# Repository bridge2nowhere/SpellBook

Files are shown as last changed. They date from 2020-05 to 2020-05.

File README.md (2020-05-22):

# SpellBook



Tabletop SpellBook for Dungeons and Dragons 5e.

This Arduino project keeps track of spell slots and spell text without having to have a phone out, spell cards, or a stack of paper/book.

# Hardware
* [Adafruit M0 Adalogger](https://www.adafruit.com/product/2796)
* [Adafruit Sharp Memory Display Breakout Board](https://www.adafruit.com/product/3502)
* [Adafruit 8x8 Mini Led Matrix with I2C backpack](https://www.adafruit.com/product/871)
* [2.7" Sharp Memory Display](https://www.digikey.com/product-detail/en/sharp-microelectronics/LS027B7DH01A/425-2908-ND/5054067) replacing the one that comes on the breakout board
* [KY-040 Rotary Encoder](https://www.aliexpress.com/item/33041814942.html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,searchweb201602_,searchweb201603_)
* [19mm Push Button](https://www.aliexpress.com/item/4000072167036.html?spm=a2g0s.9042311.0.0.64814c4dvVELMQ)
* MicroSD card

# Software
* Currently, spells data is stored in a JSON file on an SD card and parsed into spell objects in the program.
* The rotary encoder rotation moves through slots and levels (depending on rotation direction)
* When you click the encoder button it will switch to the spell side, where rotation rotates through the spells.

# 3D Printed Shell & 
* 3D printed shell is in two parts. The base still needs some work, I would like to line up the USB to the hole in the back.
* M3 Thumb Screws [amazon link](https://www.amazon.com/gp/product/B06XQBPD4Z/ref=ppx_yo_dt_b_asin_title_o04_s01?ie=UTF8&psc=1)
* 50mm donut semiprecious gemstone pendant for the knob [eBay link](https://www.ebay.com/itm/50mm-Round-Donut-Ring-Gemstone-Pendant-Loose-Beads-1pc-6-Materials-Selectable/390793341631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)
* 18x25mm semiprecious oval cabochons for the upper back panel [amazon link](https://www.amazon.com/gp/product/B07WZXCKFW/ref=ppx_yo_dt_b_asin_title_o04_s01?ie=UTF8&psc=1)
* 



# Future Plans
* Add a way to do long rests
* Adding a way to mark spells as prepared prepare spells to shorten the list.

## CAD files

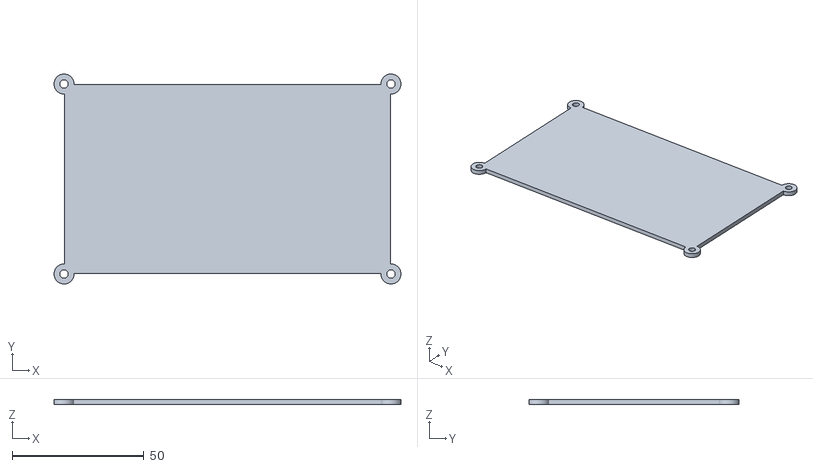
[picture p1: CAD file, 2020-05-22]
STL files/Bottom Plate v4.stl
131.9 x 79.8 x 2.00

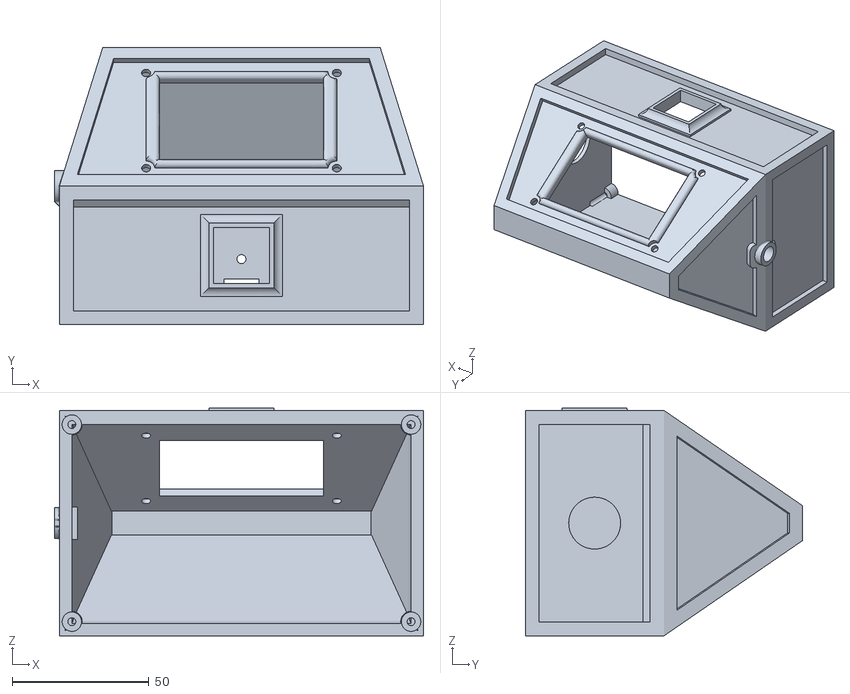
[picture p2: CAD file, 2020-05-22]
STL files/Big Screen v4.stl
135.2 x 101.6 x 83.4

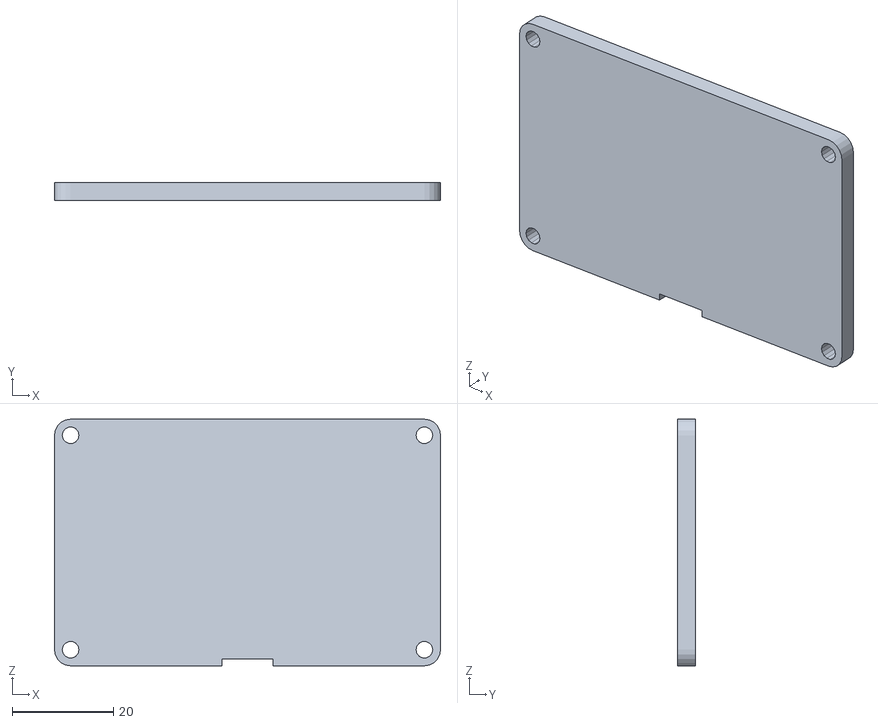
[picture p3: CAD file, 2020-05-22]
STL files/LCD Tray v2.stl
76.2 x 3.50 x 48.7

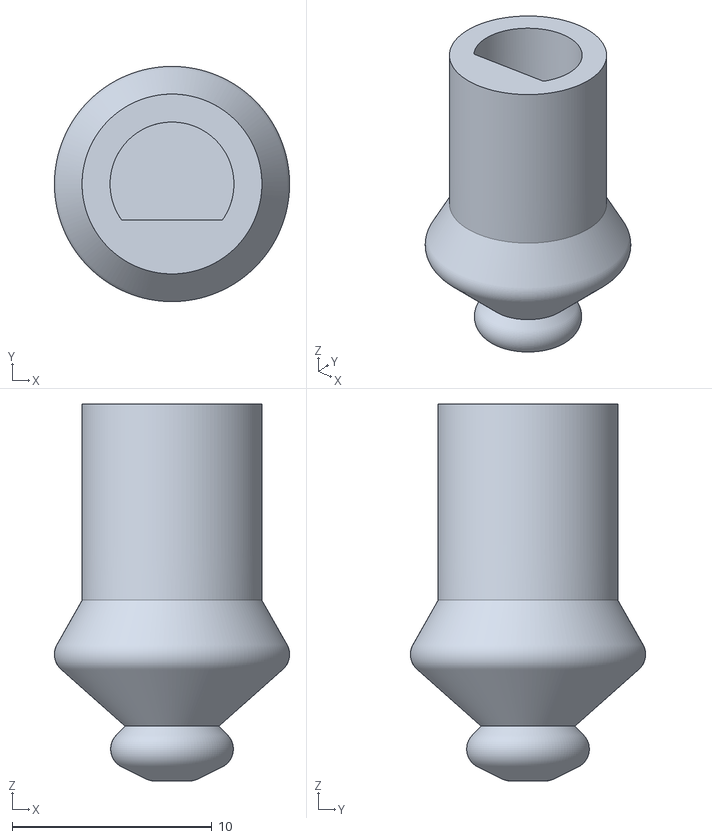
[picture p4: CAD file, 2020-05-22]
STL files/Jaspar Knob Body.stl
11.8 x 11.8 x 18.9

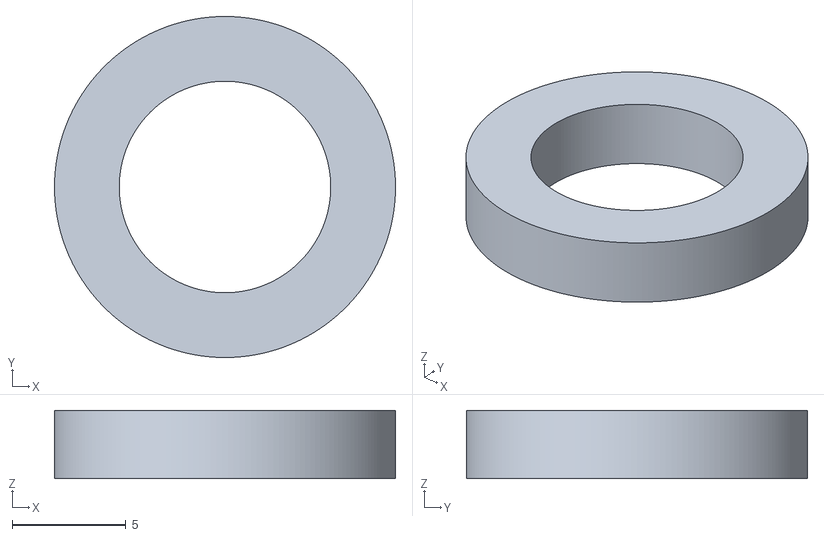
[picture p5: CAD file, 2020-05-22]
STL files/Jaspar Washer.stl
15.0 x 15.0 x 3.00

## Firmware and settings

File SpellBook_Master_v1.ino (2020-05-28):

#include <Adafruit_SharpMem.h>

#include <ArduinoJson.h>
#include "Spell.h"
#include <Wire.h>
#include <Adafruit_GFX.h>
#include <RotaryEncoder.h>
#include "Adafruit_LEDBackpack.h"
#include <Fonts/FreeSansBold12pt7b.h>
#include <Fonts/FreeSansBold9pt7b.h>
#include <Fonts/FreeSans9pt7b.h>
#include <SPI.h>
#include <SD.h>
#include <StreamUtils.h>


#define ENCODER_BUTT 6 //sw
#define ENCODER_1 5 //clk
#define ENCODER_2 9 //dt

#define SHARP_SCK  13
#define SHARP_MOSI 12
#define SHARP_SS   11

#define BLACK 0
#define WHITE 1

#define SILVER_BUTT A0

const int SPELLCOUNT = 21;
const PROGMEM char* fileNames[SPELLCOUNT] = {"0MENDING.TXT","0SACRE~1.TXT","0SPRDYIN.TXT","0THAUMAT.TXT","0TOLLDED.TXT","1DETGOOD.TXT","1DETMAGC.TXT","1DETPOSN.TXT","1GUDBOLT.TXT","1HEALWRD.TXT","1INFWOUN.TXT","1PROEVIL.TXT","1PURFOOD.TXT","1SANCTUR.TXT","1SHLDFTH.TXT","1BANE000.TXT","1BLESS000.TXT","1CEREMNY.TXT","1COMMA~1.TXT","1CRTWATR.TXT","1CUREWND.TXT"}; 

const unsigned char habbakukRelic [] PROGMEM = {
  // 'Reliquarry Picture 2, 400x240px
  0xff, 0xff, 0xff, 0xff, 0xff, 0xff, 0xff, 0xff, 0xff, 0xff, 0xff, 0xff, 0xff, 0xff, 0xff, 0xff, 
  0xff, 0xff, 0xff, 0xff, 0xff, 0xff, 0xff, 0xff, 0xff, 0xff, 0xff, 0xff, 0xff, 0xff, 0xff, 0xff, 
  0xff, 0xff, 0xff, 0xff, 0xff, 0xff, 0xff, 0xff, 0xff, 0xff, 0xff, 0xff, 0xff, 0xff, 0xff, 0xff, 
  0xff, 0xff, 0xff, 0xff, 0xff, 0xff, 0xff, 0xff, 0xff, 0xff, 0xff, 0xff, 0xff, 0xff, 0xff, 0xff, 
  0xff, 0xff, 0xff, 0xff, 0xff, 0xff, 0xff, 0xff, 0xff, 0xff, 0xff, 0xff, 0xff, 0xff, 0xff, 0xff, 
  0xff, 0xff, 0xff, 0xff, 0xff, 0xff, 0xff, 0xff, 0xff, 0xff, 0xff, 0xff, 0xff, 0xff, 0xff, 0xff, 
  0xff, 0xff, 0xff, 0xff, 0xff, 0xff, 0xff, 0xff, 0xff, 0xff, 0xff, 0xff, 0xff, 0xff, 0xff, 0xff, 
  0xff, 0xff, 0xff, 0xff, 0xff, 0xff, 0xff, 0xff, 0xff, 0xff, 0xff, 0xff, 0xff, 0xff, 0xff, 0xff, 
  0xff, 0xff, 0xff, 0xff, 0xff, 0xff, 0xff, 0xff, 0xff, 0xff, 0xff, 0xff, 0xff, 0xff, 0xff, 0xff, 
  0xff, 0xff, 0xff, 0xff, 0xff, 0xff, 0xff, 0xff, 0xff, 0xff, 0xff, 0xff, 0xff, 0xff, 0xff, 0xff, 
  0xff, 0xff, 0xff, 0xff, 0xff, 0xff, 0xff, 0xff, 0xff, 0xff, 0xff, 0xff, 0xff, 0xff, 0xff, 0xff, 
  0xff, 0xff, 0xff, 0xff, 0xff, 0xff, 0xff, 0xff, 0xff, 0xff, 0xff, 0xff, 0xff, 0xff, 0xff, 0xff, 
  0xff, 0xff, 0xff, 0xff, 0xff, 0xff, 0xff, 0xff, 0xff, 0xff, 0xff, 0xff, 0xff, 0xff, 0xff, 0xff, 
  0xff, 0xff, 0xff, 0xff, 0xff, 0xff, 0xff, 0xff, 0xff, 0xff, 0xff, 0xff, 0xff, 0xff, 0xff, 0xff, 
  0xff, 0xff, 0xff, 0xff, 0xff, 0xff, 0xff, 0xff, 0xff, 0xff, 0xff, 0xff, 0xff, 0xff, 0xff, 0xff, 
  0xff, 0xff, 0xff, 0xff, 0xff, 0xff, 0xff, 0xff, 0xff, 0xff, 0xff, 0xff, 0xff, 0xff, 0xff, 0xff, 
  0xff, 0xff, 0xff, 0xff, 0xff, 0xff, 0xff, 0xff, 0xff, 0xff, 0xff, 0xff, 0xff, 0xff, 0xff, 0xff, 
  0xff, 0xff, 0xff, 0xff, 0xff, 0xff, 0xff, 0xff, 0xff, 0xff, 0xff, 0xff, 0xff, 0xff, 0xff, 0xff, 
  0xff, 0xff, 0xff, 0xff, 0xff, 0xff, 0xff, 0xff, 0xff, 0xff, 0xff, 0xff, 0xff, 0xff, 0xff, 0xff, 
  0xff, 0xff, 0xff, 0xff, 0xff, 0xff, 0xff, 0xff, 0xff, 0xff, 0xff, 0xff, 0xff, 0xff, 0xff, 0xff, 
  0xff, 0xff, 0xff, 0xff, 0xff, 0xff, 0xff, 0xff, 0xff, 0xff, 0xff, 0xff, 0xff, 0xff, 0xff, 0xff, 
  0xff, 0xff, 0xff, 0xff, 0xff, 0xff, 0xff, 0xff, 0xff, 0xff, 0xff, 0xff, 0xff, 0xff, 0xff, 0xff, 
  0xff, 0xff, 0xff, 0xff, 0xff, 0xff, 0xff, 0xff, 0xff, 0xff, 0xff, 0xff, 0xff, 0xff, 0xff, 0xff, 
  0xff, 0xff, 0xff, 0xff, 0xff, 0xff, 0xff, 0xff, 0xff, 0xff, 0xff, 0xff, 0xff, 0xff, 0xff, 0xff, 
  0xff, 0xff, 0xff, 0xff, 0xff, 0xff, 0xff, 0xff, 0xff, 0xff, 0xff, 0xff, 0xff, 0xff, 0xff, 0xff, 
  0xff, 0xff, 0xff, 0xff, 0xff, 0xff, 0xff, 0xff, 0xff, 0xff, 0xff, 0xff, 0xff, 0xff, 0xff, 0xff, 
  0xff, 0xff, 0xff, 0xff, 0xff, 0xff, 0xff, 0xff, 0xff, 0xff, 0xff, 0xff, 0xff, 0xff, 0xff, 0xff, 
  0xff, 0xff, 0xff, 0xff, 0xff, 0xff, 0xff, 0xff, 0xff, 0xff, 0xff, 0xff, 0xff, 0xff, 0xff, 0xff, 
  0xff, 0xff, 0xff, 0xff, 0xff, 0xff, 0xff, 0xff, 0xff, 0xff, 0xff, 0xff, 0xff, 0xff, 0xff, 0xff, 
  0xff, 0xff, 0xff, 0xff, 0xff, 0xff, 0xff, 0xff, 0xff, 0xff, 0xff, 0xff, 0xff, 0xff, 0xff, 0xff, 
  0xff, 0xff, 0xff, 0xff, 0xff, 0xff, 0xff, 0xff, 0xff, 0xff, 0xff, 0xff, 0xff, 0xff, 0xff, 0xff, 
  0xff, 0xff, 0xff, 0xff, 0xff, 0xff, 0xff, 0xff, 0xff, 0xff, 0xff, 0xff, 0xff, 0xff, 0xff, 0xff, 
  0xff, 0xff, 0xff, 0xff, 0xff, 0xff, 0xff, 0xff, 0xff, 0xff, 0xff, 0xff, 0xff, 0xff, 0xff, 0xff, 
  0xff, 0xff, 0xff, 0xff, 0xff, 0xff, 0xff, 0xff, 0xff, 0xff, 0xff, 0xff, 0xff, 0xff, 0xff, 0xff, 
  0xff, 0xff, 0xff, 0xff, 0xff, 0xff, 0xff, 0xff, 0xff, 0xff, 0xff, 0xff, 0xff, 0xff, 0xff, 0xff, 
  0xff, 0xff, 0xff, 0xff, 0xff, 0xff, 0xff, 0xff, 0xff, 0xff, 0xff, 0xff, 0xff, 0xff, 0xff, 0xff, 
  0xff, 0xff, 0xff, 0xff, 0xff, 0xff, 0xff, 0xff, 0xff, 0xff, 0xff, 0xff, 0xff, 0xff, 0xff, 0xff, 
  0xff, 0xff, 0xff, 0xff, 0xff, 0xff, 0xff, 0xff, 0xff, 0xff, 0xff, 0xff, 0xff, 0xff, 0xff, 0xff, 
  0xff, 0xff, 0xff, 0xff, 0xff, 0xff, 0xff, 0xff, 0xff, 0xff, 0xff, 0xff, 0xff, 0xff, 0xff, 0xff, 
  0xff, 0xff, 0xff, 0xff, 0xff, 0xff, 0xff, 0xff, 0xff, 0xff, 0xff, 0xff, 0xff, 0xff, 0xff, 0xff, 
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
};


Adafruit_8x8matrix matrix = Adafruit_8x8matrix();
RotaryEncoder encoder(ENCODER_1, ENCODER_2);
Adafruit_SharpMem display(SHARP_SCK, SHARP_MOSI, SHARP_SS, 400, 240);

Spell* spell;

uint8_t activeSlot = 0;
int activeSpell = 0;
const uint8_t SPELL_LEVELS = 4;
uint8_t slotsMax[SPELL_LEVELS] = {4,3,3,3};
uint8_t slotsLeft[SPELL_LEVELS] = {4,3,3,3};

uint8_t currentPage = 0;

enum class knobMode : uint8_t
{
  Spells, Slots
};
knobMode knob = knobMode::Spells;


void setup() {
  Serial.begin(9600);
  //while (!Serial) {
  //  ; // wait for serial port to connect. Needed for native USB port only
  // }
  
  pinMode(ENCODER_BUTT, INPUT_PULLUP);
  pinMode(SILVER_BUTT, INPUT_PULLUP);
  matrix.begin(0x70);  // pass in the address
  matrix.setRotation(0);
  matrix.setBrightness(5);
  matrix.clear();
  matrix.writeDisplay();
  
  display.begin();
  display.clearDisplay();
  display.setRotation(2);
  display.drawBitmap(0,0,habbakukRelic,400,240,BLACK);
  display.refresh();
  delay(3000);
  display.clearDisplay();
  SD.begin(4);
  
  parseSpellJson(activeSpell);
  draw_slots(true);
  drawSpells();
}

void loop() {
  //Serial.println(tome[0]->range);
  //check encoder
  static int pos = 0;
  encoder.tick();
  int newPos = encoder.getPosition();
  if (pos != newPos){
    if(knob == knobMode::Slots) slotEncoderUpdate(pos,newPos);
    else if(knob == knobMode::Spells) spellEncoderUpdate(pos,newPos);
    Serial.println(newPos);  
    pos=newPos;
  }
  
  if(knob == knobMode::Slots) draw_slots(true);
  else if(knob == knobMode::Spells) draw_slots(false);


  if (digitalRead(ENCODER_BUTT) == LOW) {
    if(knob == knobMode::Slots) knob = knobMode::Spells;
    else if(knob == knobMode::Spells) knob = knobMode::Slots;
    delay(300);
  }

  if (digitalRead(SILVER_BUTT) == LOW) {
    currentPage ++;
    if (currentPage > 3) currentPage = 0;
    drawSpells();
  }
}

//////////////////////////////////////////////

void parseSpellJson(int spellNum) {
  
  
  File spellJSON = SD.open(fileNames[spellNum]);
  const size_t capacity = JSON_OBJECT_SIZE(12) + 1240;
  DynamicJsonDocument doc(capacity);
  deserializeJson(doc,spellJSON);
  delete spell;
  spell = new Spell(doc["name"], doc["casting_time"], doc["components"], doc["duration"], doc["level"], doc["range"], doc["ritual"], doc["school"], doc["page1"], doc["page2"], doc["page3"], doc["page4"]);
}

void draw_slots(bool showCursor) {
  matrix.clear();
  for (uint8_t lvl = 0; lvl < SPELL_LEVELS; lvl++) {
     for (uint8_t left = 0; left < slotsLeft[lvl]; left++) {
       matrix.drawPixel(2+left, lvl, LED_ON); 
     }
  }
  if (showCursor) matrix.drawPixel(0,activeSlot, LED_ON);
  matrix.writeDisplay();
}

void slotEncoderUpdate(int pos, int newPos) {
  if (pos > newPos) {
    activeSlot++;
    if (activeSlot >= SPELL_LEVELS) activeSlot = 0; 
  }
  else if (pos < newPos) {
    slotsLeft[activeSlot]--;
    if (slotsLeft[activeSlot] > 10) slotsLeft[activeSlot] = slotsMax[activeSlot];
  }
}


void spellEncoderUpdate(int pos, int newPos) {
  if (pos > newPos) {
    activeSpell++;
    if (activeSpell > SPELLCOUNT-1) activeSpell = 0; 
  }
  else if (pos < newPos) {
    activeSpell--;
    if (activeSpell < 0) activeSpell = SPELLCOUNT-1;
  }
  parseSpellJson(activeSpell);
  currentPage = 0;
  drawSpells();
}

void drawSpells(){
  display.clearDisplay();
  display.setTextColor(BLACK);
  
  display.setFont(&FreeSansBold12pt7b);
  display.setCursor(0,18);
  display.print(spell->level);
  display.print("  -  ");
  display.print(spell->spellName);
  if(spell->ritual) display.println("     RITUAL");
  else display.println("");

  display.setFont(&FreeSansBold9pt7b);
  display.setTextWrap(false);
  display.setCursor(0,36);
  display.print("Cast time: ");
  display.print(spell->casting_time);
  display.setCursor(200,36);
  display.print("Range: ");
  display.println(spell->range);
  display.setCursor(0,52);
  display.print("Components: ");
  display.print(spell->components);
  display.setCursor(200,52);
  display.print("Duration: ");
  display.println(spell->duration);

  display.setCursor(0,80);
  display.setFont(&FreeSans9pt7b);
  display.setTextColor(BLACK);
  if (currentPage == 0) display.println(spell->page0);
  else if (currentPage == 1) display.println(spell->page1);
  else if (currentPage == 2) display.println(spell->page2);
  else if (currentPage == 3) display.println(spell->page3);

  display.refresh();
  delay(300);
}

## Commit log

2020-05-22 Add STL Files for 3D printing reliquary case
    [Big Screen v4.stl, Bottom Plate v4.stl, Jaspar Knob Body.stl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]
2020-05-22 include sample json text file
2020-05-28 order files
    [Big Screen v4.stl, Bottom Plate v4.stl, Jaspar Knob Body.stl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]
